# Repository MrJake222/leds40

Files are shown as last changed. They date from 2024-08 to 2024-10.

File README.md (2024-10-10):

# LED4.0
4th edition of LED controls. ESP/WiFi based.

## Contents
* `3d` -- Enclosure,
* `board` -- PCB project,
* `board_jlc` -- 2 layer PCB project, with better attention to silk-screen,
* `esp8266` -- embedded code (platformio),
* `web` -- old-school PHP web app aggregating module controls,
* `leds41.txt` -- notes for future versions.

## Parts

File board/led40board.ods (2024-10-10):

Reference | Value | Footprint | Qty | DNP
C1 | 22uF | Capacitor_SMD:C_0805_2012Metric_Pad1.18x1.45mm_HandSolder | 1
C2 | 100uF | Capacitor_THT:CP_Radial_D6.3mm_P2.50mm | 1
D1 | LED | LED_THT:LED_D3.0mm | 1
J1 | PROG | Connector_PinHeader_2.54mm:PinHeader_2x03_P2.54mm_Vertical | 1
J2 | 6mm | Connector_BarrelJack:BarrelJack_CUI_PJ-102AH_Horizontal | 1
 | RGB | lib_MyARK:ARK_ScrewTerminal_5.00mm_4 | 1
Q1,Q2 | BC847c | Package_TO_SOT_SMD:SOT-23_Handsoldering | 2
Q3,Q4,Q5 | IRLML2502 | Package_TO_SOT_SMD:SOT-23_Handsoldering | 3
R1,R2,R3,R4 | 10K | -- mixed values -- | 4
R5 | 120 | Resistor_THT:R_Axial_DIN0204_L3.6mm_D1.6mm_P7.62mm_Horizontal | 1
U1 | ESP-12S | lib_ESP-12S:esp | 1
U2 | AMS1117-3.3 | Package_TO_SOT_SMD:SOT-223-3_TabPin2 | 1

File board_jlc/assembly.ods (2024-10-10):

Lp | Ref | Value | SMD
1 | C1 | 22uF | back
2 | R3 | 10K | back
3 | R4 | 10K | back
4 | U2 | AMS1117-3.3 | back
5 | R1 | 10K | back
6 | Q1 | BC847c | back
7 | Q2 | BC847c | back
8 | U1 | ESP-12S | back
9 | Q3 | IRLML2502 | front
10 | Q4 | IRLML2502 | front
11 | Q5 | IRLML2502 | front
12 | R2 | 10K | front | 10K smd mało jest
13 | R5 | 120 | front
14 | J1 | 2x3 goldpin
15 | J3 | 4x ARK
16 | C2 | 100uF
17 | J2 | DC jack 5,5x2,1
18 | D1 | LED

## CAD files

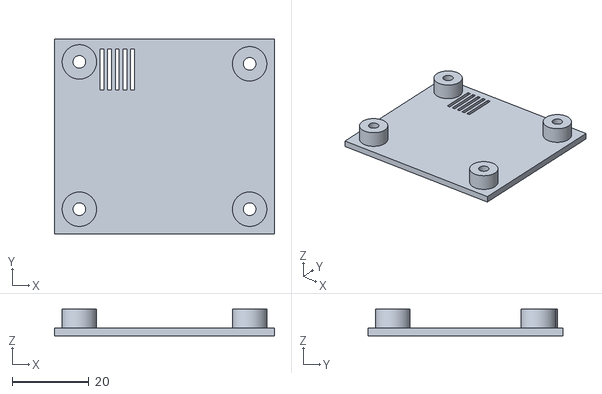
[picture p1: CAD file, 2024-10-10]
3d/led40_case_v11_btm.stl
57.5 x 51.0 x 7.00

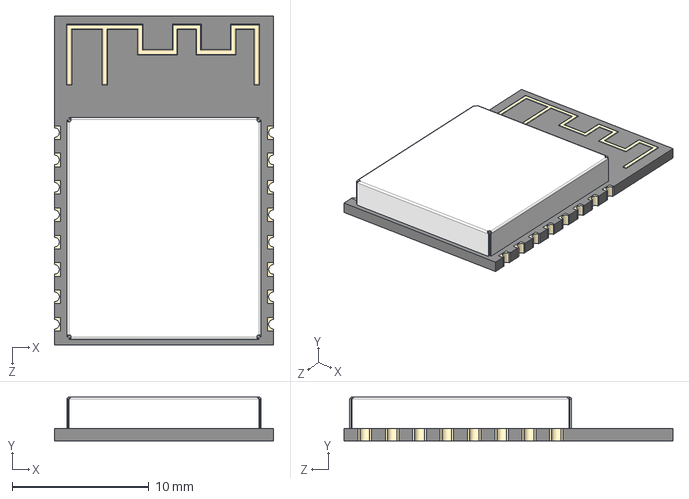
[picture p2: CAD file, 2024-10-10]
board/lib_ESP-12S/ESP-12S.step
16.0 x 3.20 x 24.0 mm

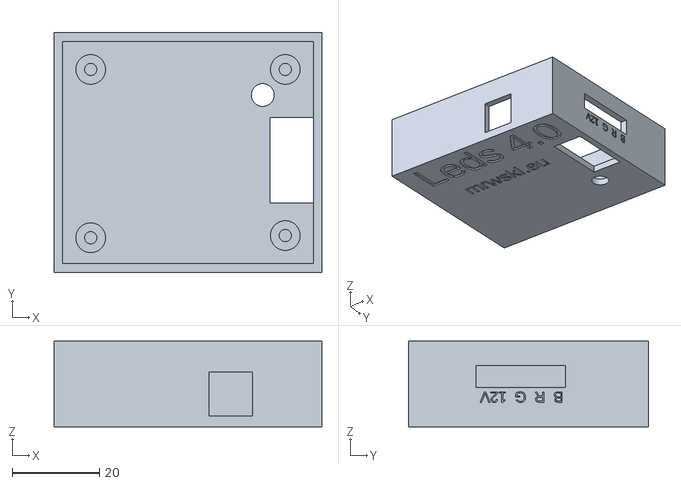
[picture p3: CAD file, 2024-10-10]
3d/led40_case_v3_top.stl
61.3 x 54.8 x 19.6

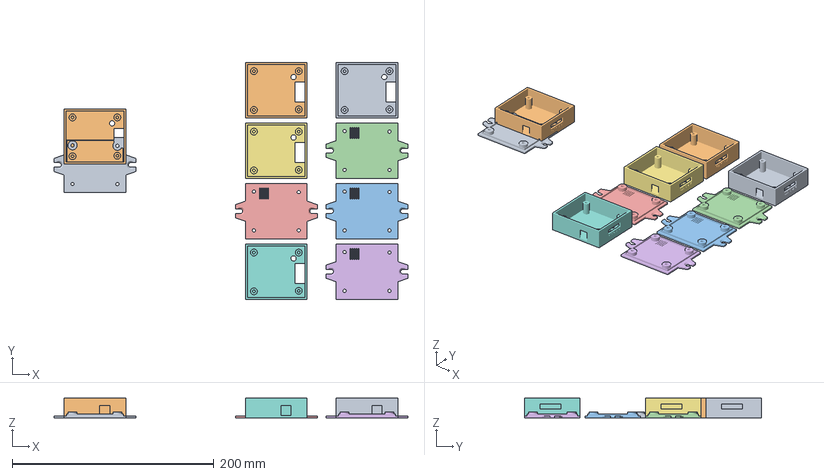
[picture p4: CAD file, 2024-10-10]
3d/led40_case_v3_curaproj.3mf
351.3 x 234.8 x 19.6 mm
led40_case_v3_btm.stl
led40_case_v3_top.stl
led40_case_v3_btm.stl(1)
led40_case_v3_btm.stl(2)
led40_case_v3_btm.stl(3)
led40_case_v3_btm.stl(4)
led40_case_v3_top.stl(1)
led40_case_v3_top.stl(2)
led40_case_v3_top.stl(3)
led40_case_v3_top.stl(4)

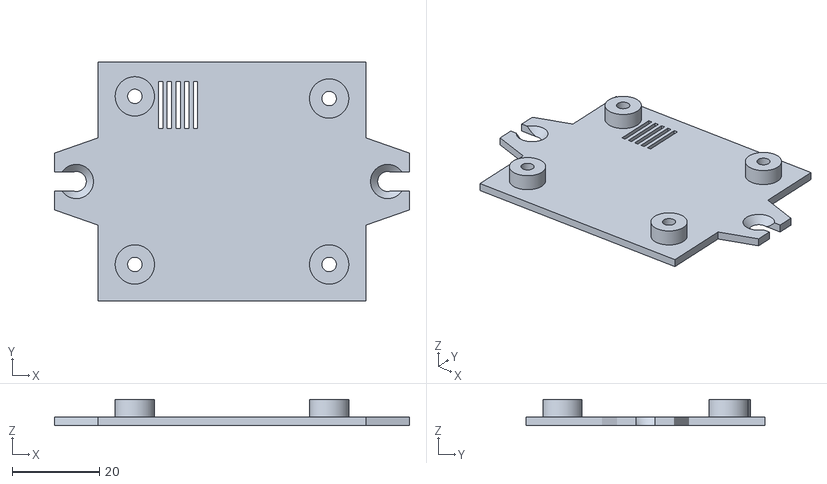
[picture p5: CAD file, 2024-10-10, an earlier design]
3d/led40_case_v2_btm.stl
81.3 x 54.8 x 6.00

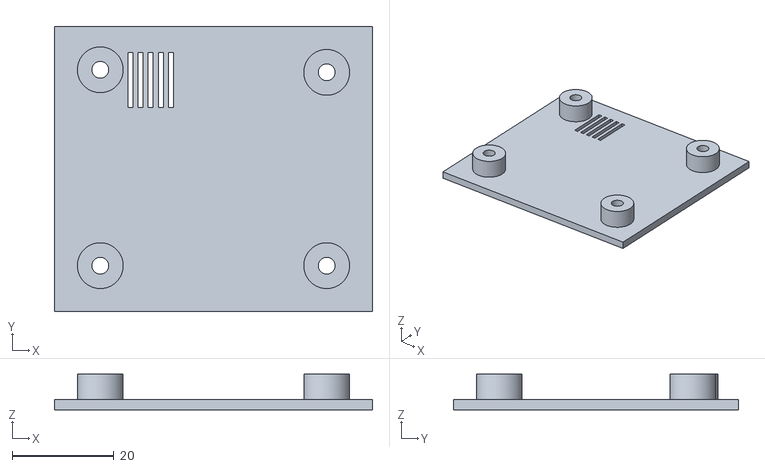
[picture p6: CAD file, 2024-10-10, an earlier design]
3d/led40_case_v1_btm.stl
62.5 x 56.0 x 7.00

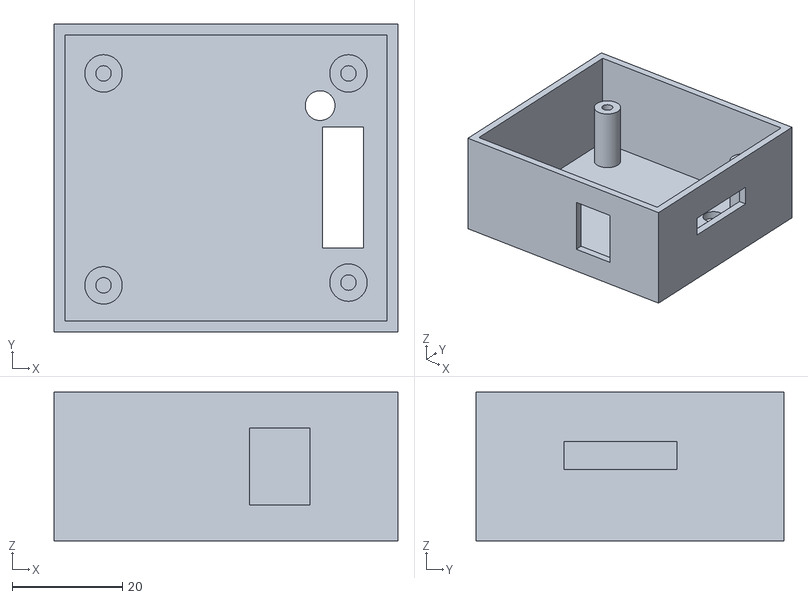
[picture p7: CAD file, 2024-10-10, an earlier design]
3d/led40_case_v1_top.stl
62.5 x 56.0 x 27.0

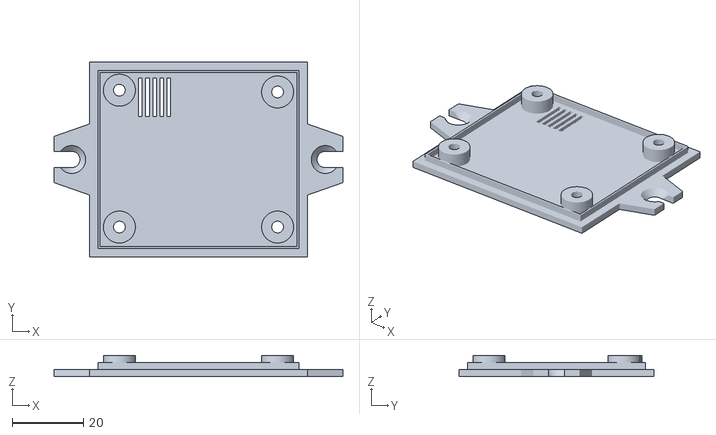
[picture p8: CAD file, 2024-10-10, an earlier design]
3d/led40_case_v3_btm.stl
81.3 x 54.8 x 6.00

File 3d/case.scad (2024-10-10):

include <helpers.scad>
include <screw.scad>
$fn=$preview ? 16 : 128;

x=56.5;
y=50.0;
z=14; // height (bottom board - bottom top)

W=2; // wall thickness
G=0.4; // wall gap
E=4; // elements bottom gap

// print indexes
TOP=0; BTM=1;

mx = [6, 6,     x-6, x-6];
my = [6, y-5.5, y-6, 6  ];

module mounts() {
    for (i = [0:3])
    translate([mx[i], my[i], -E]) {
        screw_hole_3x12(W, rot=180);
        //color("blue") cylinder(h=15, r=S3x12_D_th/2);
    }
}

module fins(n) {
    for (i = [0:4])
        translate([i*2, 0, 0])
        cube([1, 10.8, 10]);
}

module jack() { translate([33,   35.8,  3.5])    cube([10, 15.4+10, 10]); }
module ark()  { translate([45.5, 16.48, W])      cube([8+10,  20.5, 5]); }
module ascr() { translate([47, 17, 0])           cube([x+G-47, 19.5, 30]); }
module led()  { translate([45.35, 11.85, 0])     cylinder(r=2.6, h=15+10);  }
module ldo()  { translate([12.4-1, 38.1-1, -10]) fins(); }

module atxt() {
    translate([x+G+W-0.5, 17, 8])
    rotate([90, 0, 90])
    linear_extrude(1)
    text("B  R  G  12V", 2.5);
}

module logo() {
    translate([2.5, y-10, z+2-0.5])
    linear_extrude(1) {
        text("Leds 4.0", 10);
        
        translate([7, -11, 0])
            text("mrwski.eu", 5);
    }
}
//color("green") logo();

module board() {
    color("red") {
        // this is the board that must fit
        cube([x, y, 2]);
        mounts();
        jack();
        ark();
        led();
        ascr(); // ark screws
        atxt(); // ark text
        ldo();
        logo();
    }
}

module ear(rot) {
    R=2.2;
    rotate(rot)
    translate([-10, -5, 0])
    difference() {
        linear_extrude(W)
            polygon(points=[[0,0],[3.5,10],[10-R,10],[10-R,5.5],[10+R,5.5],[10+R,10],[16.5,10],[20,0]]);
        translate([10, 5, -0.1])
            cylinder(r1=R, r2=4, h=W+0.2);
    }
}

module case(print) {
    o=W+G;  // side offset
    bo=E-G; // bottom offset
    if (print==TOP) {
        translate([-o,  -o,   z]) cube([o+x+o, o+y+o, W]); // top
        translate([-o,  -o,  -bo]) cube([o+x+o, W, bo+z]); // front
        translate([x+G, -o,  -bo]) cube([W, o+y+o, bo+z]); // right
        translate([-o,  -o,  -bo]) cube([W, o+y+o, bo+z]); // left
        translate([-o,  y+G, -bo]) cube([o+x+o, W, bo+z]); // back
    }
    else {
        color("gray") {
            translate([-o, -o, -(W+E)]) cube([o+x+o, o+y+o, W]); // bottom
            translate([-o-5,   y/2, -(W+E)]) ear(90);
            translate([ o+5+x, y/2, -(W+E)]) ear(-90);
        }
        
        // pilot, size of the board
        w=0.5;
        h=E/2;
        color("cyan") {
            translate([0,   0,   -E]) cube([x, w, h]); // front
            translate([x-w, 0,   -E]) cube([w, y, h]); // right
            translate([0,   0,   -E]) cube([w, y, h]); // left
            translate([0,   y-w, -E]) cube([x, w, h]); // back
        }
    }
    
    // screws
    for (i = [0:3])
    translate([mx[i], my[i], 0]) {
        // long sockets
        if (print==TOP) translate([0, 0, W]) screw_socket(S3x12_D, S3x12_W, z, round=true);
        // supports
        else translate([0, 0, -E]) cylinder_hollow(h=E, ri=S3x12_D_th/2, ro=4.5);
    }
}

module merge(print) {
    difference() {
        case(print);
        board();
    }
}
//board();

rotate([180, 0, 0]) merge(TOP);
//merge(BTM);
//merge(TOP);

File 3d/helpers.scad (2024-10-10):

module cylinder_vert(h, r) {
    rotate([90, 0, 0])
        cylinder(h=h, r=r, center=true);
}

module cylinder_hollow(h, ri, ro, center) {
    difference() {
        cylinder(h=h, r=ro, center=center);
        translate([0, 0, -0.5])
          cylinder(h=h+1, r=ri, center=center);
    }
}

module half_cube(diag, l, h) {
    side = diag / sqrt(2);
    
    difference() {
        cube([side, l, side]);
        
        translate([0, -1, 0]) {
            rotate([0, -45, 0])
                cube([diag, l+2, diag/2+0.001]);
                
            rotate([0, -45, 0])
            translate([0, 0, -diag/2-h])
                cube([diag, l+2, diag/2+0.001]);
        }
    }
    
    
} 

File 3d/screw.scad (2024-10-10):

module screw_socket(d, w, h, round=false) {
    // d -- inner screw hole diameter
    // w -- wall width
    // h -- height of socket
    
    // outer cube side
    a = d + 2*w;
    
    translate([0, 0, h/2])
    difference() {
      if (round) cylinder(r=a/2, h=h, center=true);
      else cube([a, a, h], center=true);
    
      color("red")
        cylinder(r=d/2, h=h+1, center=true);
    }
}

module screw_hole(d1, d2, h, rot=0) {
  // d1 -- bottom, smaller diameter (screw passes through it)
  // d2 -- top, larger diameter (screw head stops on it)
  // h -- height of wall to penetrate
  // rot -- rotation
  
  rotate([rot, 0, 0])
    cylinder(r1=d1/2, r2=d2/2, h=h);
}

S3x12_D = 2.8;
S3x12_D_th = 3.3; // through
S3x12_D_top = 5.7+0.5; // top head
S3x12_W = 2;
S3x12_H = 11;
module screw_socket_3x12(round=false) {
  screw_socket(S3x12_D, S3x12_W, S3x12_H, round);
}
module screw_hole_3x12(h, rot=0) {
  // h -- wall width
  // rot -- rotation
  screw_hole(S3x12_D_th, S3x12_D_top, h=h+0.001, rot=rot);
}

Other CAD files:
3d/led40_case_v2_top.stl

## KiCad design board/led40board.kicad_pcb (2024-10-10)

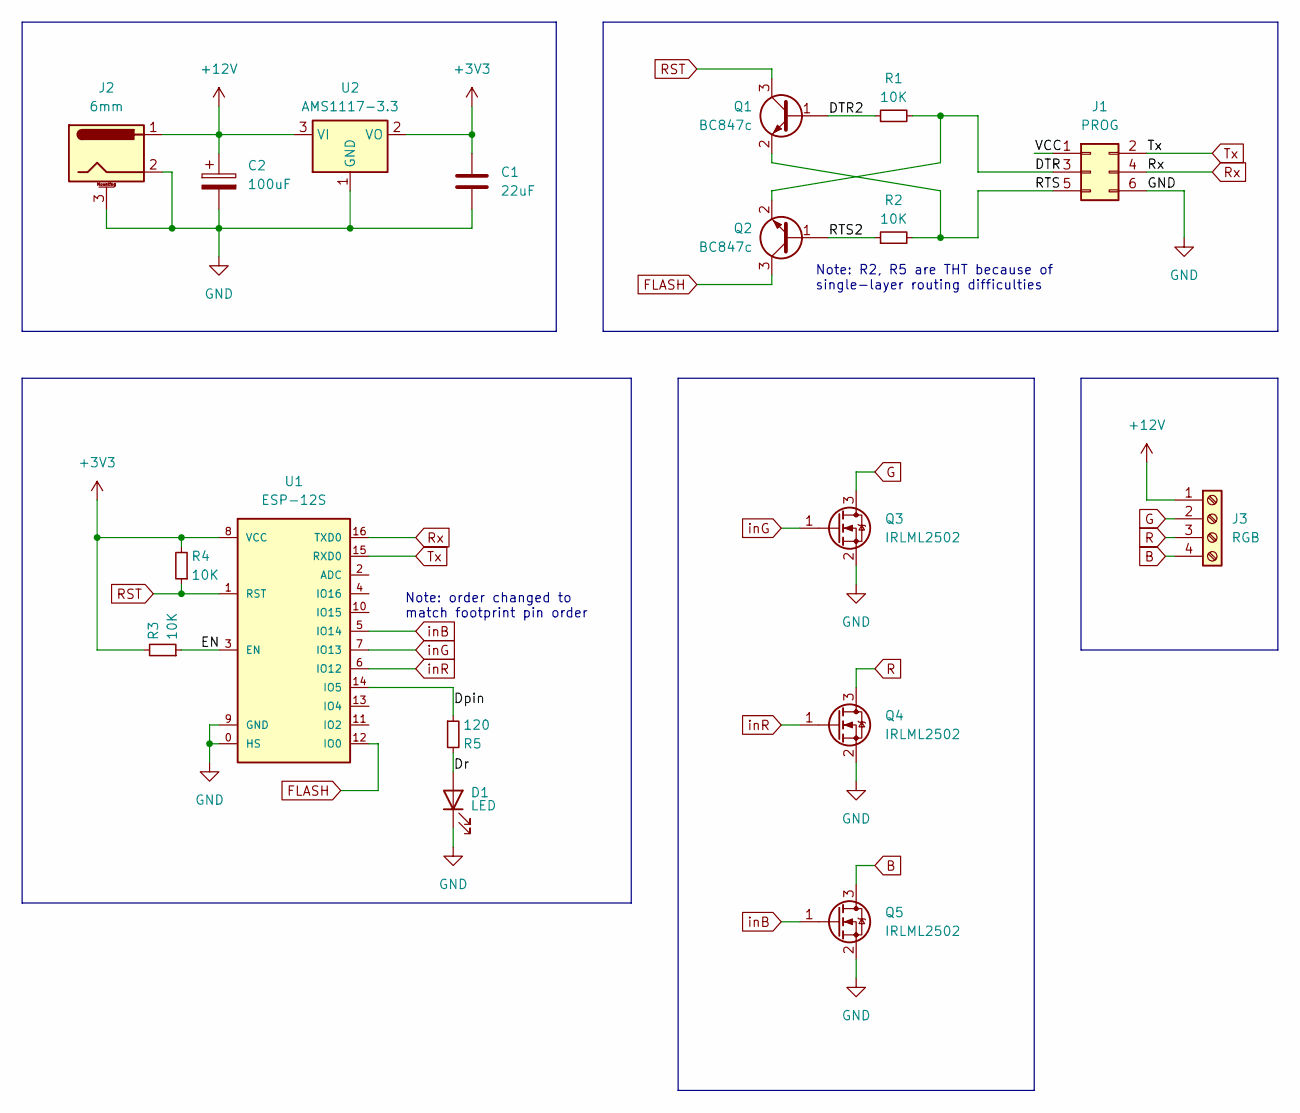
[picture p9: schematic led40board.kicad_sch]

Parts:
C1: 22uF; C_0805_2012Metric_Pad1.18x1.45mm_HandSolder
C2: 100uF; CP_Radial_D6.3mm_P2.50mm
D1: LED; LED_D3.0mm
J1: PROG; PinHeader_2x03_P2.54mm_Vertical
J2: 6mm; BarrelJack_CUI_PJ-102AH_Horizontal
J3: RGB; ARK_ScrewTerminal_5.00mm_4
Q1, Q2: BC847c; SOT-23_Handsoldering
Q3, Q4, Q5: IRLML2502; SOT-23_Handsoldering
R1, R3, R4: 10K; R_0603_1608Metric_Pad0.98x0.95mm_HandSolder
R2: 10K; R_Axial_DIN0204_L3.6mm_D1.6mm_P7.62mm_Horizontal
R5: 120; R_Axial_DIN0204_L3.6mm_D1.6mm_P7.62mm_Horizontal
U1: ESP-12S; esp
U2: AMS1117-3.3; SOT-223-3_TabPin2

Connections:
+3V3: C1.1, R3.2, R4.2, U1.8 (VCC), U2.2 (VO)
+12V: C2.1, J2.1, J3.1, U2.3 (VI)
/DTR: J1.3, Q2.2 (E), R1.2
/DTR2: Q1.1 (B), R1.1
/Dpin: R5.1, U1.14 (IO5)
/Dr: D1.2 (A), R5.2
/EN: R3.1, U1.3 (EN)
/RTS: J1.5, Q1.2 (E), R2.2
/RTS2: Q2.1 (B), R2.1
/VCC: J1.1
B: J3.4, Q5.3 (D)
FLASH: Q2.3 (C), U1.12 (IO0)
G: J3.2, Q3.3 (D)
GND: C1.2, C2.2, D1.1 (K), J1.6, J2.2, J2.3 (MountPin), Q3.2 (S), Q4.2 (S), Q5.2 (S), U1.0 (HS), U1.9 (GND), U2.1 (GND)
R: J3.3, Q4.3 (D)
RST: Q1.3 (C), R4.1, U1.1 (RST)
Rx: J1.4, U1.16 (TXD0)
Tx: J1.2, U1.15 (RXD0)
inB: Q5.1 (G), U1.5 (IO14)
inG: Q3.1 (G), U1.7 (IO13)
inR: Q4.1 (G), U1.6 (IO12)

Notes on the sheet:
Note: R2, R5 are THT because of single-layer routing difficulties
Note: order changed to match footprint pin order

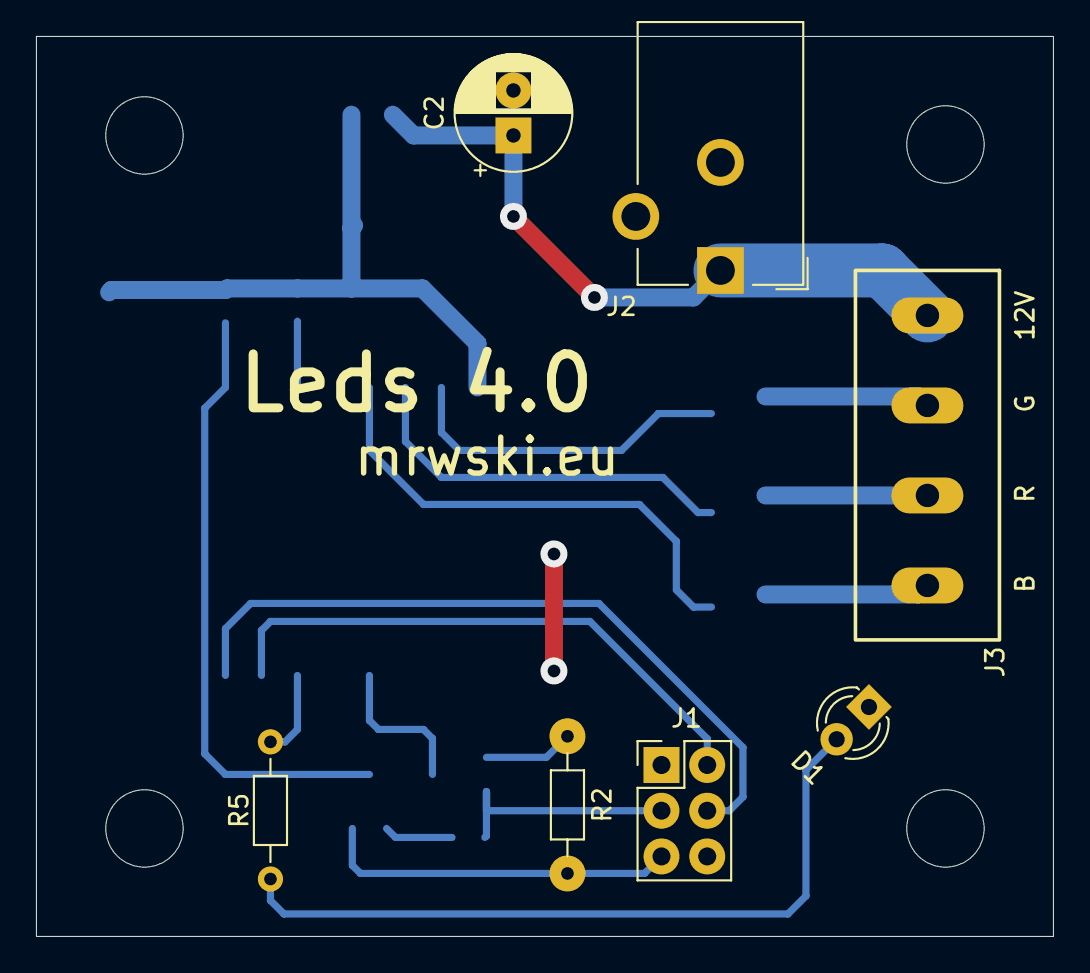
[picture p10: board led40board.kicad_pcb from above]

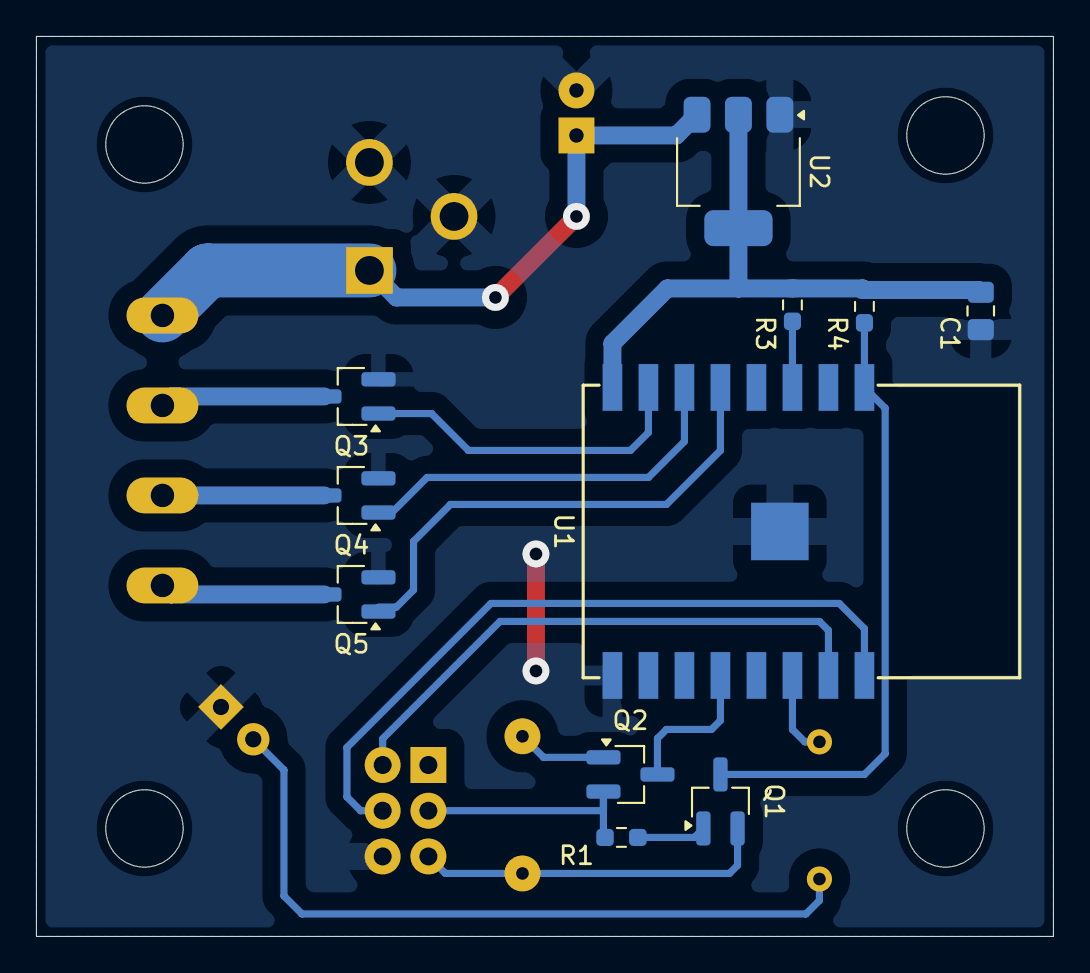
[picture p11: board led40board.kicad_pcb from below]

Board: 2 copper layers, 56.5 x 50.0 mm, 22 parts (11 on the bottom side), 20 nets.

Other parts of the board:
MNT: 4.3mm; MountingHole_4.3mm_M4
MNT#2, MNT#3, MNT#4: 4.3mm; MountingHole_4.3mm_M4

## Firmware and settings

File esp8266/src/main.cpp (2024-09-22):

#include <Arduino.h>
#include <SimpleFTPServer.h>

#include <hw.hpp>

#include <logger.hpp>
#include <ledstatus.hpp>
#include <ledstrip.hpp>
#include <wifimng.hpp>
#include <wifievents.hpp>
#include <server.hpp>

void config_changed();

// control classes
mrwski::Logger logger;
mrwski::LEDStatus ledst(LED_STATUS);
mrwski::Name name;
wl_status_t sta_fail_reason;
mrwski::WifiEvents wifiev(logger);
mrwski::WifiMng wifimng(logger, ledst, config_changed, sta_fail_reason);
mrwski::Server server(logger, wifimng, name, 80, config_changed, sta_fail_reason);
FtpServer ftp;

// functionality
// injects its routes to server
mrwski::LEDStrip leds(server, LED_R, LED_G, LED_B);

int fs_init() {
    bool ok = LittleFS.begin();
    if (!ok) {
        logger.println("failed to setup FS");
        return 1;
    }

    logger.println("FS init ok");

    fs::FSInfo i;
    LittleFS.info(i);
    logger.printf("Used: %d / %d bytes (free %d bytes)\n", i.usedBytes, i.totalBytes, i.totalBytes - i.usedBytes);

    // logger.println("files present:");
    // listAllFilesInDir("/");
    // logger.println("");

    return 0;
}

#define NTP_SERVER "pl.pool.ntp.org"
#define TZ "CET-1CEST,M3.5.0,M10.5.0/3"

// TODO route injection to Server
// TODO led control + simple frontend
// TODO web: display system time
// TODO web: reset button

int ftp_cli;
void ftp_cb(FtpOperation ftpOperation, uint freeSpace, uint totalSpace) {
    switch (ftpOperation) {
        case FTP_CONNECT:
            ftp_cli++;
            break;

        case FTP_DISCONNECT:
            ftp_cli--;
            break;

        case FTP_FREE_SPACE_CHANGE:
            break;
    }
}

void setup() {
    Serial.begin(115200);
    Serial.println();
    logger.begin_serial(Serial);

    fs_init();
    logger.begin_fs("/log");

    leds.begin();
    ledst.begin();

    wifimng.begin();
    wifiev.register_events();

    server.begin();

    ftp_cli = 0;
    ftp.begin("norbert", "marcel!!");
    ftp.setCallback(ftp_cb);
    ftp.setLocalIp(WiFi.softAPIP());

    configTime(TZ, NTP_SERVER);
}

void config_changed() {
    server.restart();
    ftp.setLocalIp(WiFi.localIP());
}

void loop() {
    wifimng.loop();
    server.loop();
    ledst.loop();
    ftp.handleFTP();

    if (WiFi.status() == WL_CONNECTED && ftp_cli == 0) {
        // if wifi is connected and ftp has no clients
        // and web server reports no activity long periods of time
        // delay to enter light sleep mode, 75mA -> 35mA current draw reduction
        // and less heat from AMS1117
        if (server.ms_since_last_conn() > 5e3)
            delay(250); // 5 seconds -> 250ms delays
    }
}

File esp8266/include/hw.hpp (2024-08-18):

#pragma once

#define LED_STATUS   5
#define LED_R       12
#define LED_G       13
#define LED_B       14

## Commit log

2024-08-20 control led, power saving light sleep
2024-09-15 Led routes & simple web interface
2024-09-22 Fixes
    MAC address display in status
    better styling
    correct name fetching
    [main.cpp]
2024-10-10 added 3d files
    [case.scad, helpers.scad, led40_case_v11_btm.stl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]
2024-10-10 added boards
    [ESP-12S.step, assembly.ods, led40board.kicad_pcb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]
